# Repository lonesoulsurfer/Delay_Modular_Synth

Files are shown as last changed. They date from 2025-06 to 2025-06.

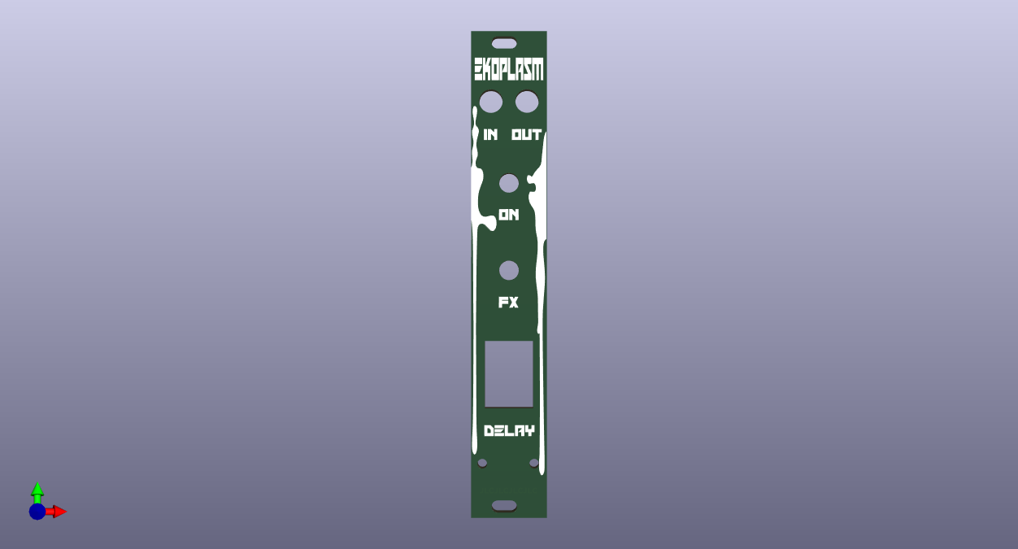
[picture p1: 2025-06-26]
Front Panel Design/Ekoplasm - Front Panel Kicad.png

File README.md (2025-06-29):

# Delay_Modular_Synth

thumbnail_Photoroom_20250612_161436

Vid of the modular in action
https://www.youtube.com/watch?v=E-r9soOqiS8

Adding delay to any synth can add fantastic depth to the sonic soundscape. This build uses an Arduino Nano to create a digtal delay that can be used on a modular synths or as it's own stand along synth. It's an easy build with minimal components needed and the finished module sounds great!

The original schematic (see below) had some additional features which I removed as they didn't sound great with my modular synth set-up.  I had to also make a change to the values of 2 capacitors connected to the input and output audio sockets as I was getting too much feedback.  This doesn't effect the delay at all and removes most if not all of the noise.

Original build
https://projecthub.arduino.cc/CesarSound/echotrek-digital-delay-echo-audio-effects-with-arduino-c4f2fd

Just a quick note on my modular synth. The one that I built is a bit of a cheats version where most of the modules are powered by an Arduino Nano. It means that I don't have to worry about tuning, playing around with 1v/octave controlled voltages etc. Everything is always in tune and simple to use in my cheats modular synth :)

I've got a little space left in my current Eurorack to add another module which will either be a low pass filter or a sync in/sync out.

thumbnail_Photoroom_20250612_161633

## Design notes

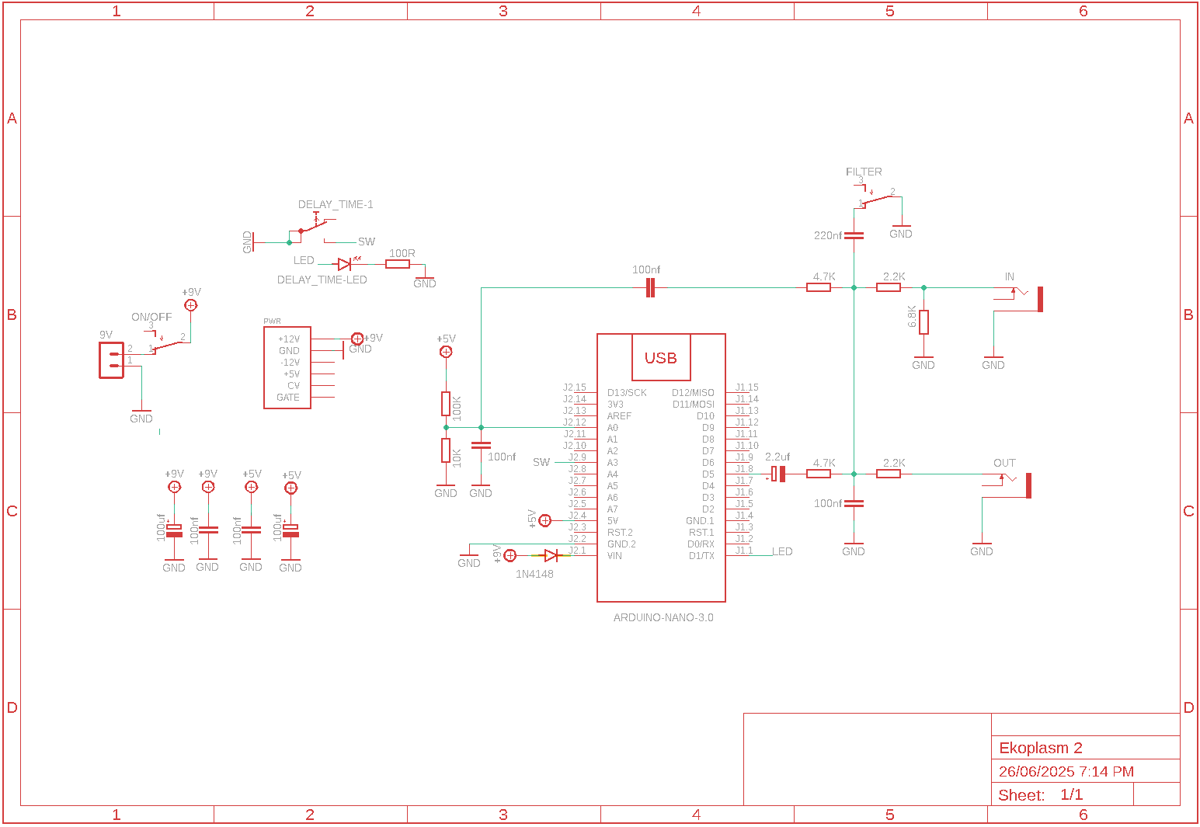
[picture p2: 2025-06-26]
Schematic.png

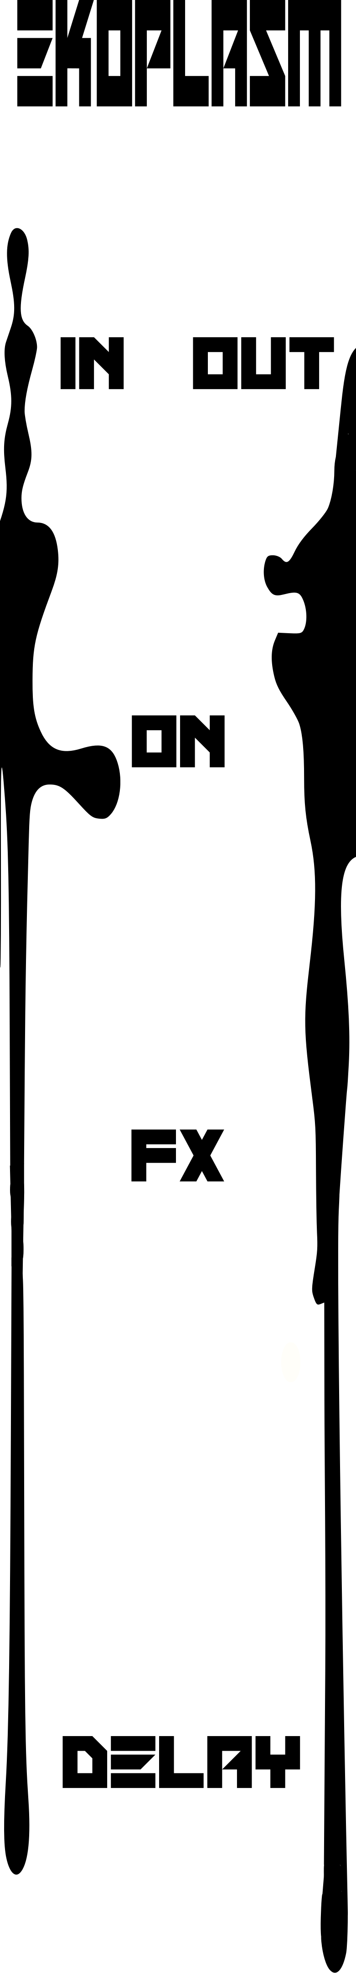
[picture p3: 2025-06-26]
Front Panel Design/Ekoplasm -Front Panel Inkscape.png

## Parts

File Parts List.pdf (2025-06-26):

Part | Type | Value | Qty | Link | Image
| | 100nf | 6
| | 220nf | 1
| electrolyte ers | 2.2uf | 1 | Link (https://vi.aliexpress.com/w/wholesale-capacitor-esr.html?spm=a2g0o.productlist.search.0)
| | 100uf | 2
Diode | 1N4148 | | 1 | Link (https://vi.aliexpress.com/w/wholesale-1n4148.html?spm=a2g0o.productlist.search.0)
Resistor | Metal Film | 10K | 1 | Link (https://vi.aliexpress.com/w/wholesale-resistor-metal-film.html?spm=a2g0o.productlist.search.0)
| | 100K | 1
| | 4.7K | 2
| | 2.2K | 2
| | 6.8K | 1
| | 100R | 1
Switch | Toggle (stitch pin end) | | 2 | Link (https://vi.aliexpress.com/item/1005001510219617.html)
| momentary PB86-A1 | | 1 | Link (https://vi.aliexpress.com/item/32969818198.html?src=google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)
Audio Socket | PJ301M | | 2 | Link (https://vi.aliexpress.com/item/1005005352992401.html?scm_id=1007.40050.354490.0&scm-url=1007.40050.354490.0)

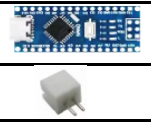
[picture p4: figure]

Arduino Nano | | | 1 | Link (https://vi.aliexpress.com/w/wholesale-arduino-nano.html?spm=a2g0o.detail.search.0)
Socket and wire | JST PH 2.00mm | | 1 | Link (https://vi.aliexpress.com/item/1005005939956886.html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)

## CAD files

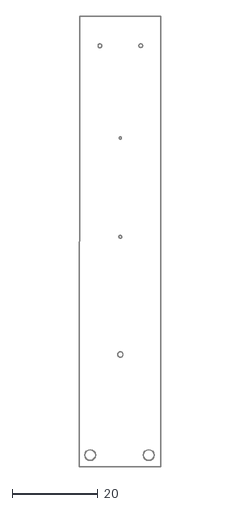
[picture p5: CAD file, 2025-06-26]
Front Panel Design/Ekoplasm PCB.dxf
19.1 x 105.5

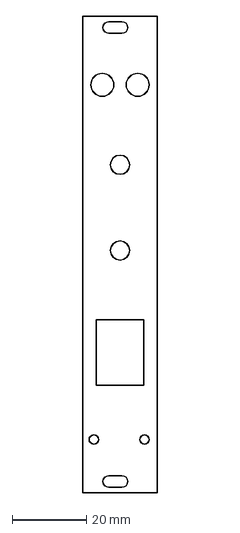
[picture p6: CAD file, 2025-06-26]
Front Panel Design/Ekoplasm fusion.dxf
20.0 x 128.5 mm

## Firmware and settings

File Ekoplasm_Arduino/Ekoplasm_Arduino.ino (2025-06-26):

#define  audio_in A0
#define time_selector A3

const unsigned int d_size = 1900;  //Delay memory buffer size
unsigned int val, d_val, d_time;
int i, j;
byte  count = 2;
bool rev = 0;
char delay_data[d_size + 1] = { NULL };  //Delay  memory buffer
char delay_data_1[d_size + 1] = { NULL };  //Delay memory buffer
  

void setup() {
  pinMode(time_selector, INPUT_PULLUP);
  DDRD = B00000010;
  DDRB = B11100000;
  InitTimer1();           //Set up timer 1 for 16.384kHz
  setPwmFrequency(5, 1);  //function for setting PWM High frequency 62.475kHz on  pin D5
  analogReference(INTERNAL);   //Use 1.1v aref voltage.
  up_time();
}

void  loop() {
  if (digitalRead(time_selector) == LOW) {
    up_time();
    PORTB  = B11100000;   //make pin 13 high and power on the led when pushbutton is pressed
    while (digitalRead(time_selector) == LOW);
  } else PORTB = B11000000;   //make  pin 13 low and power off the led pushbutton is released
  if (rev) PORTD = B00000000;  else PORTD = B00000010;   //Reverse speech sampler indication TX Led power on
}

void  sampling() {
  val = map(analogRead(audio_in), 0, 900, 0, 255);
  delay_sound();
  analogWrite(5, d_val);
}

void delay_sound() {
  i = i + 1; if (i  > d_time) i = 0;
  delay_data[i] = val;
  if (i == d_time) j = 0;
  delay_data_1[i]  = delay_data[i];
  j = j + 1; if (j > d_time) j = 0;
  if (!rev) d_val = delay_data_1[j];
  if (rev) d_val = delay_data_1[d_time - j];
}

void up_time() {
  noInterrupts();
  count++;
  if (count > 7)
    count = 1;
  delay(20);

  switch  (count)  {
    case 1:
      d_time = 400; rev = 0; //63ms
      break;
    case 2:
      d_time = 700; //110ms
      break;
    case 3:
      d_time  = 1000; //158ms
      break;
    case 4:
      d_time = 1300; //205ms
      break;
    case 5:
      d_time = 1600; //253ms
      break;
    case 6:
      d_time = 1900; //300ms
      break;
    case 7:
      d_time  = 1500; rev = 1; //Reverse speech
      break;
  } interrupts();
}

//Set  up timer 1 for 16.384kHz (975)
void InitTimer1() {
  cli(); //Disable global  interrupts
  TCCR1A = 0; //Reset Timer 1 Counter Control Register A
  TCCR1B  = 0; //Reset Timer 1 Counter Control Register B
  TCNT1  = 0; //initialize counter  value to 0
  OCR1A = 975; //Set Timer 1 to desired frequency: 16384Hz (16,000,000  / 16384) - 1 = 975
  //Turn on CTC (clear timer on compare match) mode:
  TCCR1B  |= (1 << WGM12);
  TCCR1B |= (1 << CS10); //CS10 Prescalar = 1 (no prescalar  used); CS11 Prescalar = 8
  TIMSK1 |= (1 << OCIE1A); //Enable timer interrupt
  sei(); //Enable interrupts
}

ISR(TIMER1_COMPA_vect) {
  sampling();
}

//PWM  62.475kHz high frequency DAC for pins 5 & 6 (others are 32k)
void setPwmFrequency(int  pin, int divisor) {
  byte mode;
  if (pin == 5 || pin == 6 || pin == 9 ||  pin == 10) {
    switch (divisor) {
      case 1: mode = 0x01; break;
      case 8: mode = 0x02; break;
      case 64: mode = 0x03; break;
      case  256: mode = 0x04; break;
      case 1024: mode = 0x05; break;
      default:  return;
    }
    if (pin == 5 || pin == 6) {
      TCCR0B = TCCR0B & 0b11111000  | mode;
    } else {
      TCCR1B = TCCR1B & 0b11111000 | mode;
    }
  } else if (pin == 3 || pin == 11) {
    switch (divisor) {
      case 1:  mode = 0x01; break;
      case 8: mode = 0x02; break;
      case 32: mode  = 0x03; break;
      case 64: mode = 0x04; break;
      case 128: mode = 0x05;  break;
      case 256: mode = 0x06; break;
      case 1024: mode = 0x07; break;
      default: return;
    }
    TCCR2B = TCCR2B & 0b11111000 | mode;
  }
}
